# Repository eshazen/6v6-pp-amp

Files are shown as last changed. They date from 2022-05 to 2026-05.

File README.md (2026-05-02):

# 10 WPC 6V6 push-pull amp

This is a proposed build of an amp for TV sound.  I've been using a
6V6 single-ended amp, which is OK but perhaps a little wimpy for this
application.  The Dynaco A-410 EL84/6V6 schematic looks like a nice,
classic option.

As of 2026-04-02:

DigiKey parts are about $560 including iron.

Tubes:

    JJ 6SL7 2 @ $26.95  $45
    JJ 6V6  4 @ $23.95  $96
    JJ GZ34 1 @ $21.95  $22
                 Total $163

PCBs from JLC almost $200 with shipping.
<br>PCBGOGO $178 with shipping
				 
So around $950 total without chassis. Amps are now expensive!

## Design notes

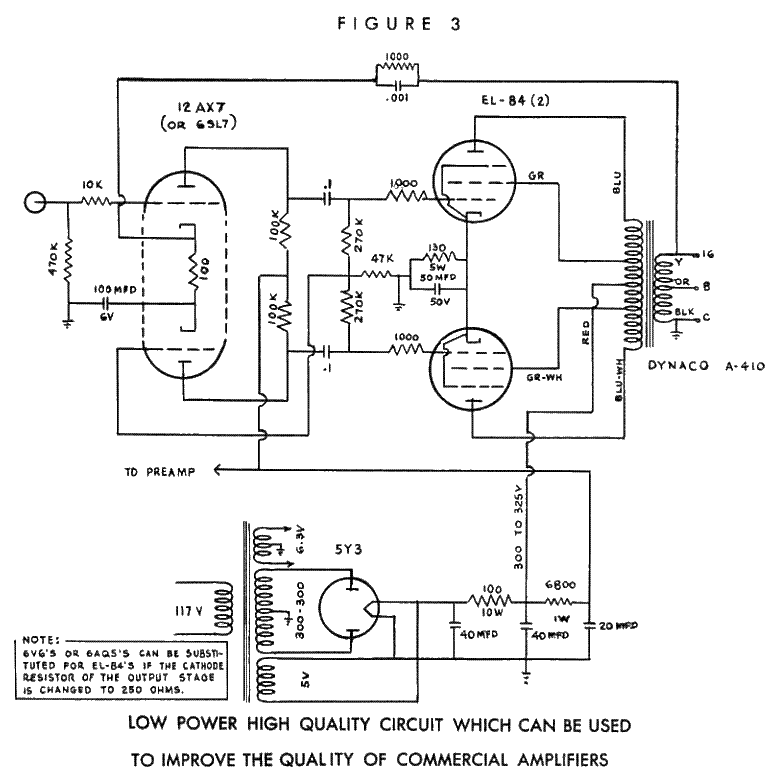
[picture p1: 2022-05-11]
reference/Push-Pull-EL84-6BQ5-6V6-6AQ5-Dynaco-A-410-Tube-Amp-Schematic.png

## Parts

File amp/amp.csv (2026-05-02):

Reference | Value | Qty | DNP | CatNo
C1,C9 | 1000p | 2 |  | 399-5448-1-ND
C2,C10 | 100u 16V | 2 |  | 732-8598-1-ND
C3,C11 | 22u 350V | 2 |  | 493-12650-1-ND
C4,C5,C12,C13 | 0.22u 400V | 4 |  | 338-3444-ND
C6 | 47uF 450V | 1 |  | 399-15673-ND
C7,C14 | 470u 50V | 2 |  | 493-12789-1-ND
C8,C15 | 47u 450V | 2 |  | 399-15673-ND
F1 | Fuse | 1 |  | Mouser 504-BK/HBH-I-R
H1,H2,H3,H4 | MountingHole | 4
J1,J3 | RCA | 2 |  | PJRAN1X1U03X-ND
J2 | Conn_01x05 | 1 |  | 486-1007-ND
J4,J5 | JPR_2x3 | 2 |  | 2057-PH2-06-UA-ND
JP1 | JPR3 | 1 |  | WM4621-ND
LS1,LS2 | Speaker | 2 |  | 36-4109-ND
NE1 | Lamp_Neon | 1 |  | A1A-ND
R1,R15 | 470K | 2 |  | 470KW-1-ND
R2,R4,R16,R18 | 100K | 4 |  | 100KW-1-ND
R3,R17 | 100 | 2 |  | 100W-1-ND
R5,R10,R14,R19,R24,R27 | 1k | 6 |  | RSA-1.0KRCT-ND
R6,R20 | 6.8k 1W | 2 |  | 6.8KW-1-ND
R7,R9,R21,R23 | 270K | 4 |  | 270KW-1-ND
R8,R22 | 47K | 2 |  | 47KW-1-ND
R11,R13,R26 | 100R 20W | 3 |  | B20J100E-ND
R12,R25 | 250 | 2 |  | PPC1D250CT-ND
R28 | 100k | 1 |  | 100KW-1-ND
SW1 | SW_SPST_GND | 1 |  | 563-1727-ND
SW2,SW3 | SW_SPDT | 2 |  | 563-1727-ND
T1 | Transformer_Hammond_272HX | 1 |  | HM5012-ND
T2,T3 | Hammond 1608A | 2 |  | HM4113-ND
U1,U5 | 6SL7 | 2 |  | AES P-ST8-193
U2 | GZ34 | 1 |  | AES P-ST8-193
U3,U4,U6,U7 | 6V6 | 4 |  | AES P-ST8-193

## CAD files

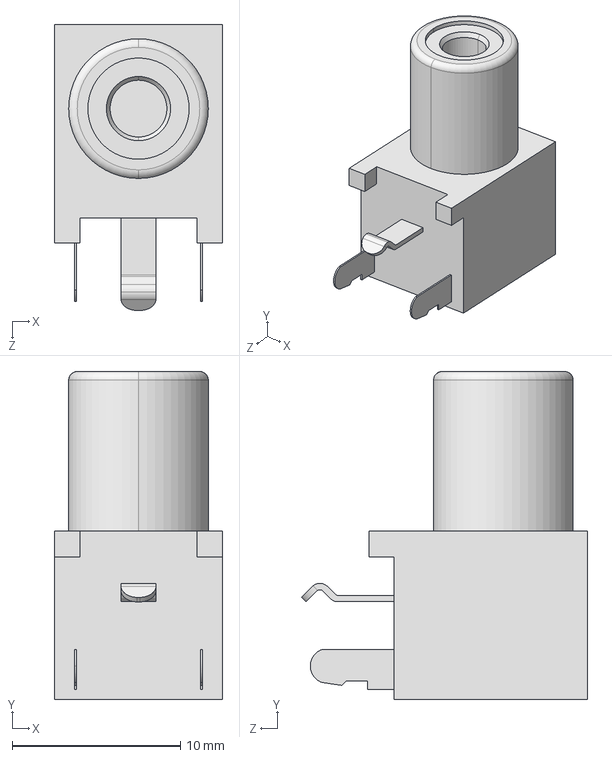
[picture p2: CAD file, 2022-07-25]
amp/3D/pjran1x1_Series.STEP
10.00 x 19.5 x 17.0 mm

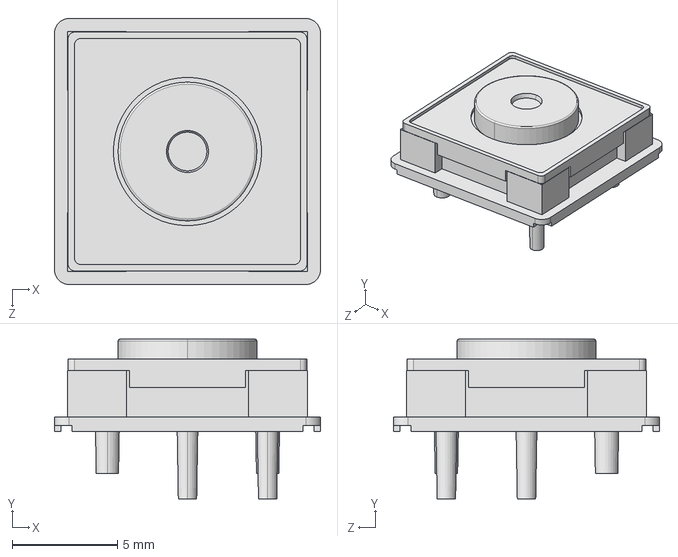
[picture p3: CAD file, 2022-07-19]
amp/3D/1241.1002.STEP
12.7 x 7.60 x 12.7 mm

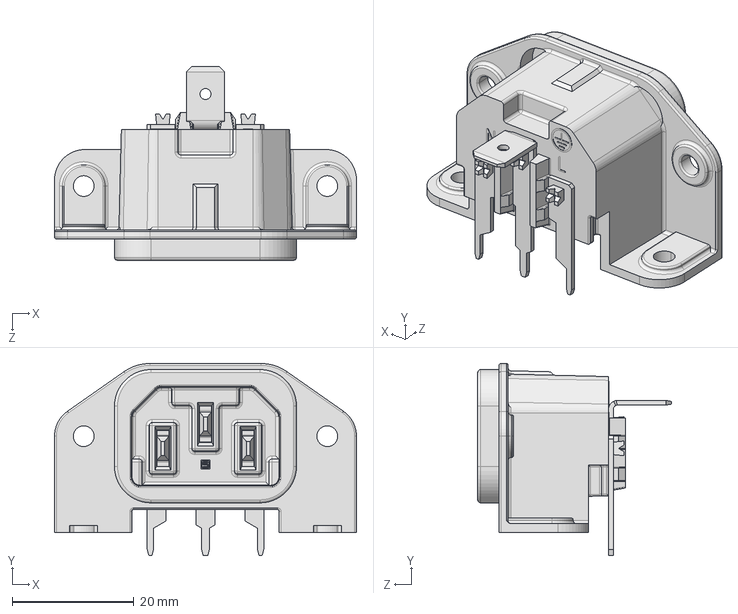
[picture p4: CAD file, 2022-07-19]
amp/3D/e_0100.2041d003.step
49.6 x 31.6 x 31.8 mm

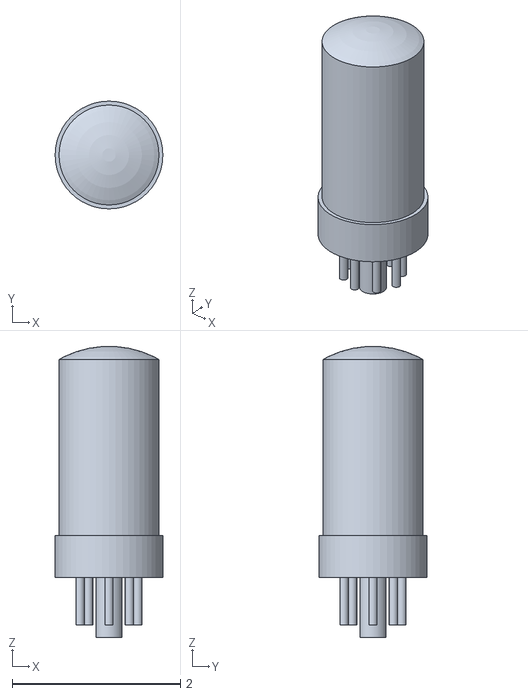
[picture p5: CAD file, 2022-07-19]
amp/3D/6sl7.stl
1.28 x 1.28 x 3.46

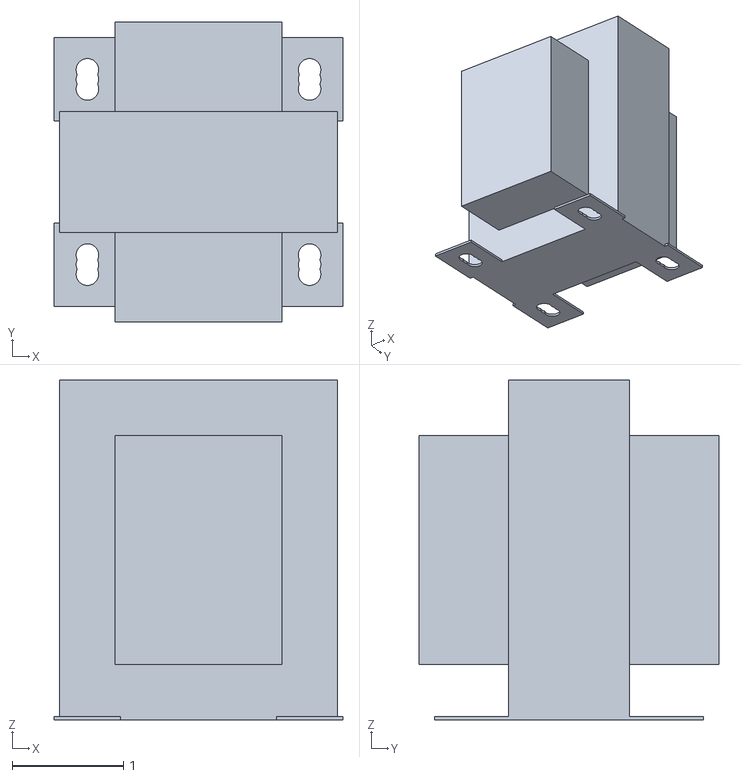
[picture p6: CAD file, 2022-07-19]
amp/3D/hammond_1608a.stl
2.60 x 2.70 x 3.06

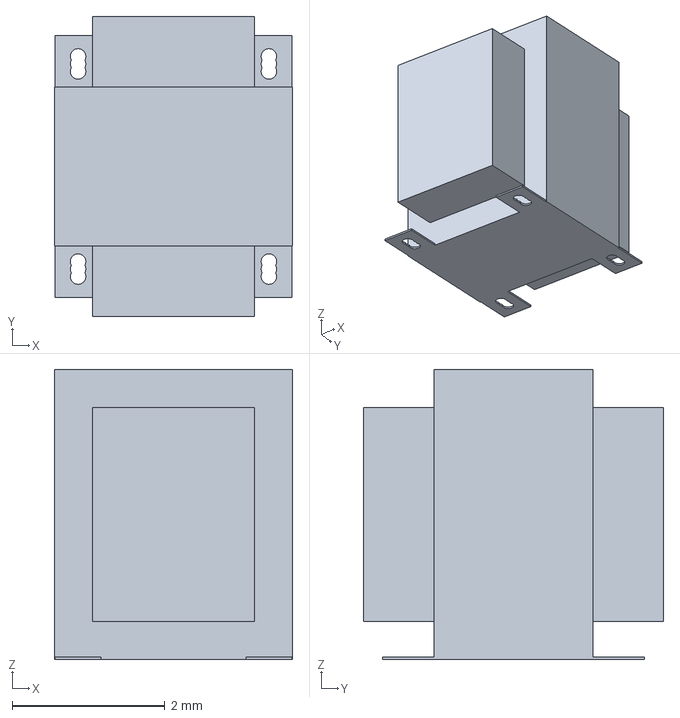
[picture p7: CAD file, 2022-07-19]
amp/3D/hammond_272hx.3mf
3.12 x 3.94 x 3.80 mm

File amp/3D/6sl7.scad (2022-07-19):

/* Generic octal tube */

e = 0.001;
$fn=48;

base_dia = 1+9/32;
tube_dia = 1+3/16;
overall_height = 3+5/16;
working_height = 2.75;

base_height = 0.5;

glass_height = working_height-base_height;
pin_len = overall_height-working_height;

/* must be >2 */
sphere_dia = 2.05 * tube_dia;

pin_rad = (11/16) / 2;
pin_dia = 0.1;
post_dia = 5/16;
post_len = pin_len + 0.15;

pstep = 360/8;

module tube() {
     /* base */
     color("black")
	  cylinder( h=base_height, d=base_dia);
     /* glass with rounded top */
     color( [0.5, 0.5, 0.5, 0.75])
     intersection() {
	  cylinder( h=working_height, d=tube_dia);
	  translate( [0, 0, working_height-sphere_dia/2])
	       sphere( d=sphere_dia);
     }
     /* array of pins */
     color("silver")
     for( i= [0: 8]) {
	  rotate( [0, 0, i*pstep])
	       translate( [pin_rad, 0, -pin_len])
	       cylinder( r=pin_dia/2, h=pin_len);
     }

     /* post */
     color("black")
     translate( [0, 0, -post_len])
	  cylinder( d=post_dia, h=post_len);
}



tube();

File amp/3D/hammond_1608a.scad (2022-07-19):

/* Hammond 1608A audio */


$fn=32;
e = 0.001;

/* datasheet dims */
A = 2.500;
B = 2.700;
C = 3.060;;
D = 2.000;
E = 1.667;
GX = 0.203;
GY = 0.375;

/* core dims (estimated) */
core_X = A;
core_Y = E-GY-0.2;
core_Z = C;

/* bell dims (estimated) */
bell_X = A-1.0;
bell_Y = B;
bell_Z = C-1.0;
bell_up = 0.5;

/* mounting tabs */
tab_X = 0.6;
tab_Y = 0.75;
tab_Z = 0.03125;

module tab() {
     difference() {
	  cube( [tab_X, tab_Y, tab_Z]);
	  translate( [tab_X/2, tab_Y/2+GY/2-GX/2, -e])
	       cylinder( d=GX, h=tab_Z+2*e);
	  translate( [tab_X/2, tab_Y/2-GY/2+GX/2, -e])
	       cylinder( d=GX, h=tab_Z+2*e);
	  translate( [tab_X/2, tab_Y/2, -e])
	       cylinder( d=GX, h=tab_Z+2*e);
     }
}

module 272hx() {
     color( [0.3, 0.3, 0.3]) {
	  /* core */
	  translate( [-core_X/2, -core_Y/2, 0])
	       cube( [core_X, core_Y, core_Z]);
	  /* bell */
	  translate( [-bell_X/2, -bell_Y/2, bell_up])
	       cube( [bell_X, bell_Y, bell_Z]);
	  translate( [-(D/2)-tab_X/2, -E/2-tab_Y/2, 0])
	       tab();
	  translate( [(D/2)-tab_X/2, -E/2-tab_Y/2, 0])
	       tab();
	  translate( [-(D/2)-tab_X/2, E/2-tab_Y/2, 0])
	       tab();
	  translate( [(D/2)-tab_X/2, E/2-tab_Y/2, 0])
	       tab();
     }
}


272hx();

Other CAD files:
amp/3D/hammond_272hx.scad
amp/3D/hammond_272hx.stl

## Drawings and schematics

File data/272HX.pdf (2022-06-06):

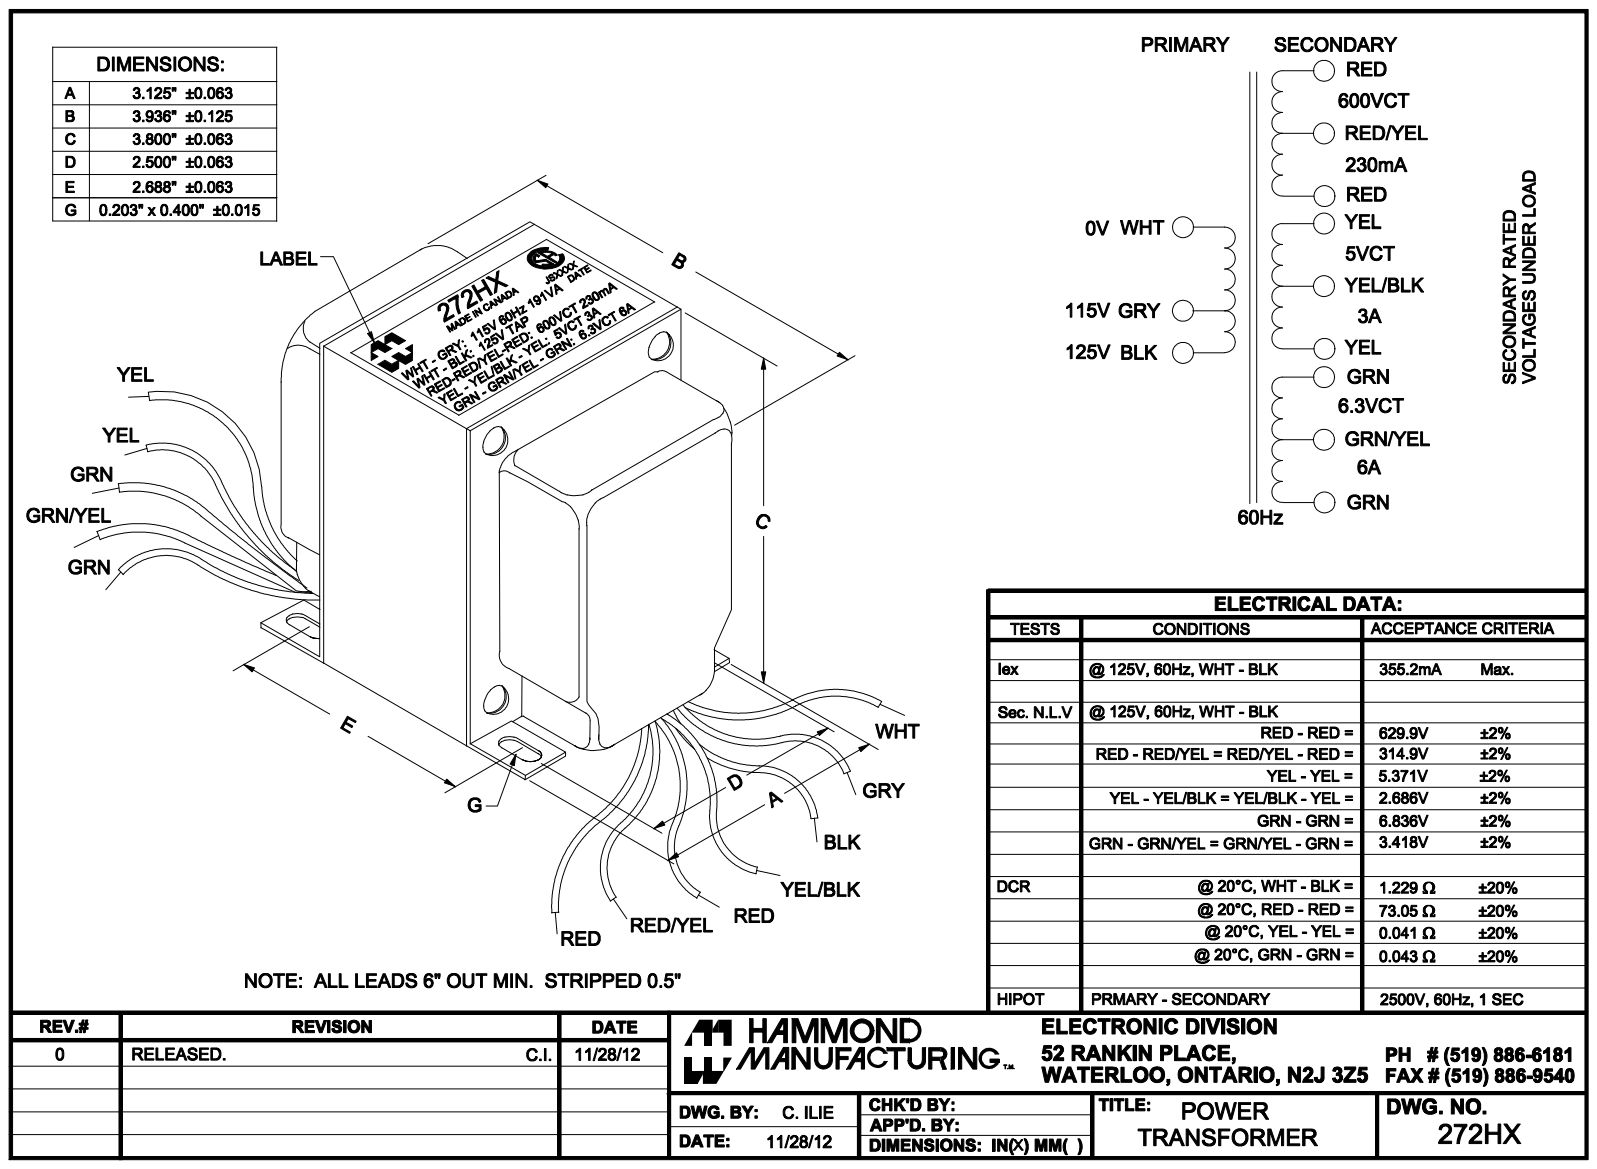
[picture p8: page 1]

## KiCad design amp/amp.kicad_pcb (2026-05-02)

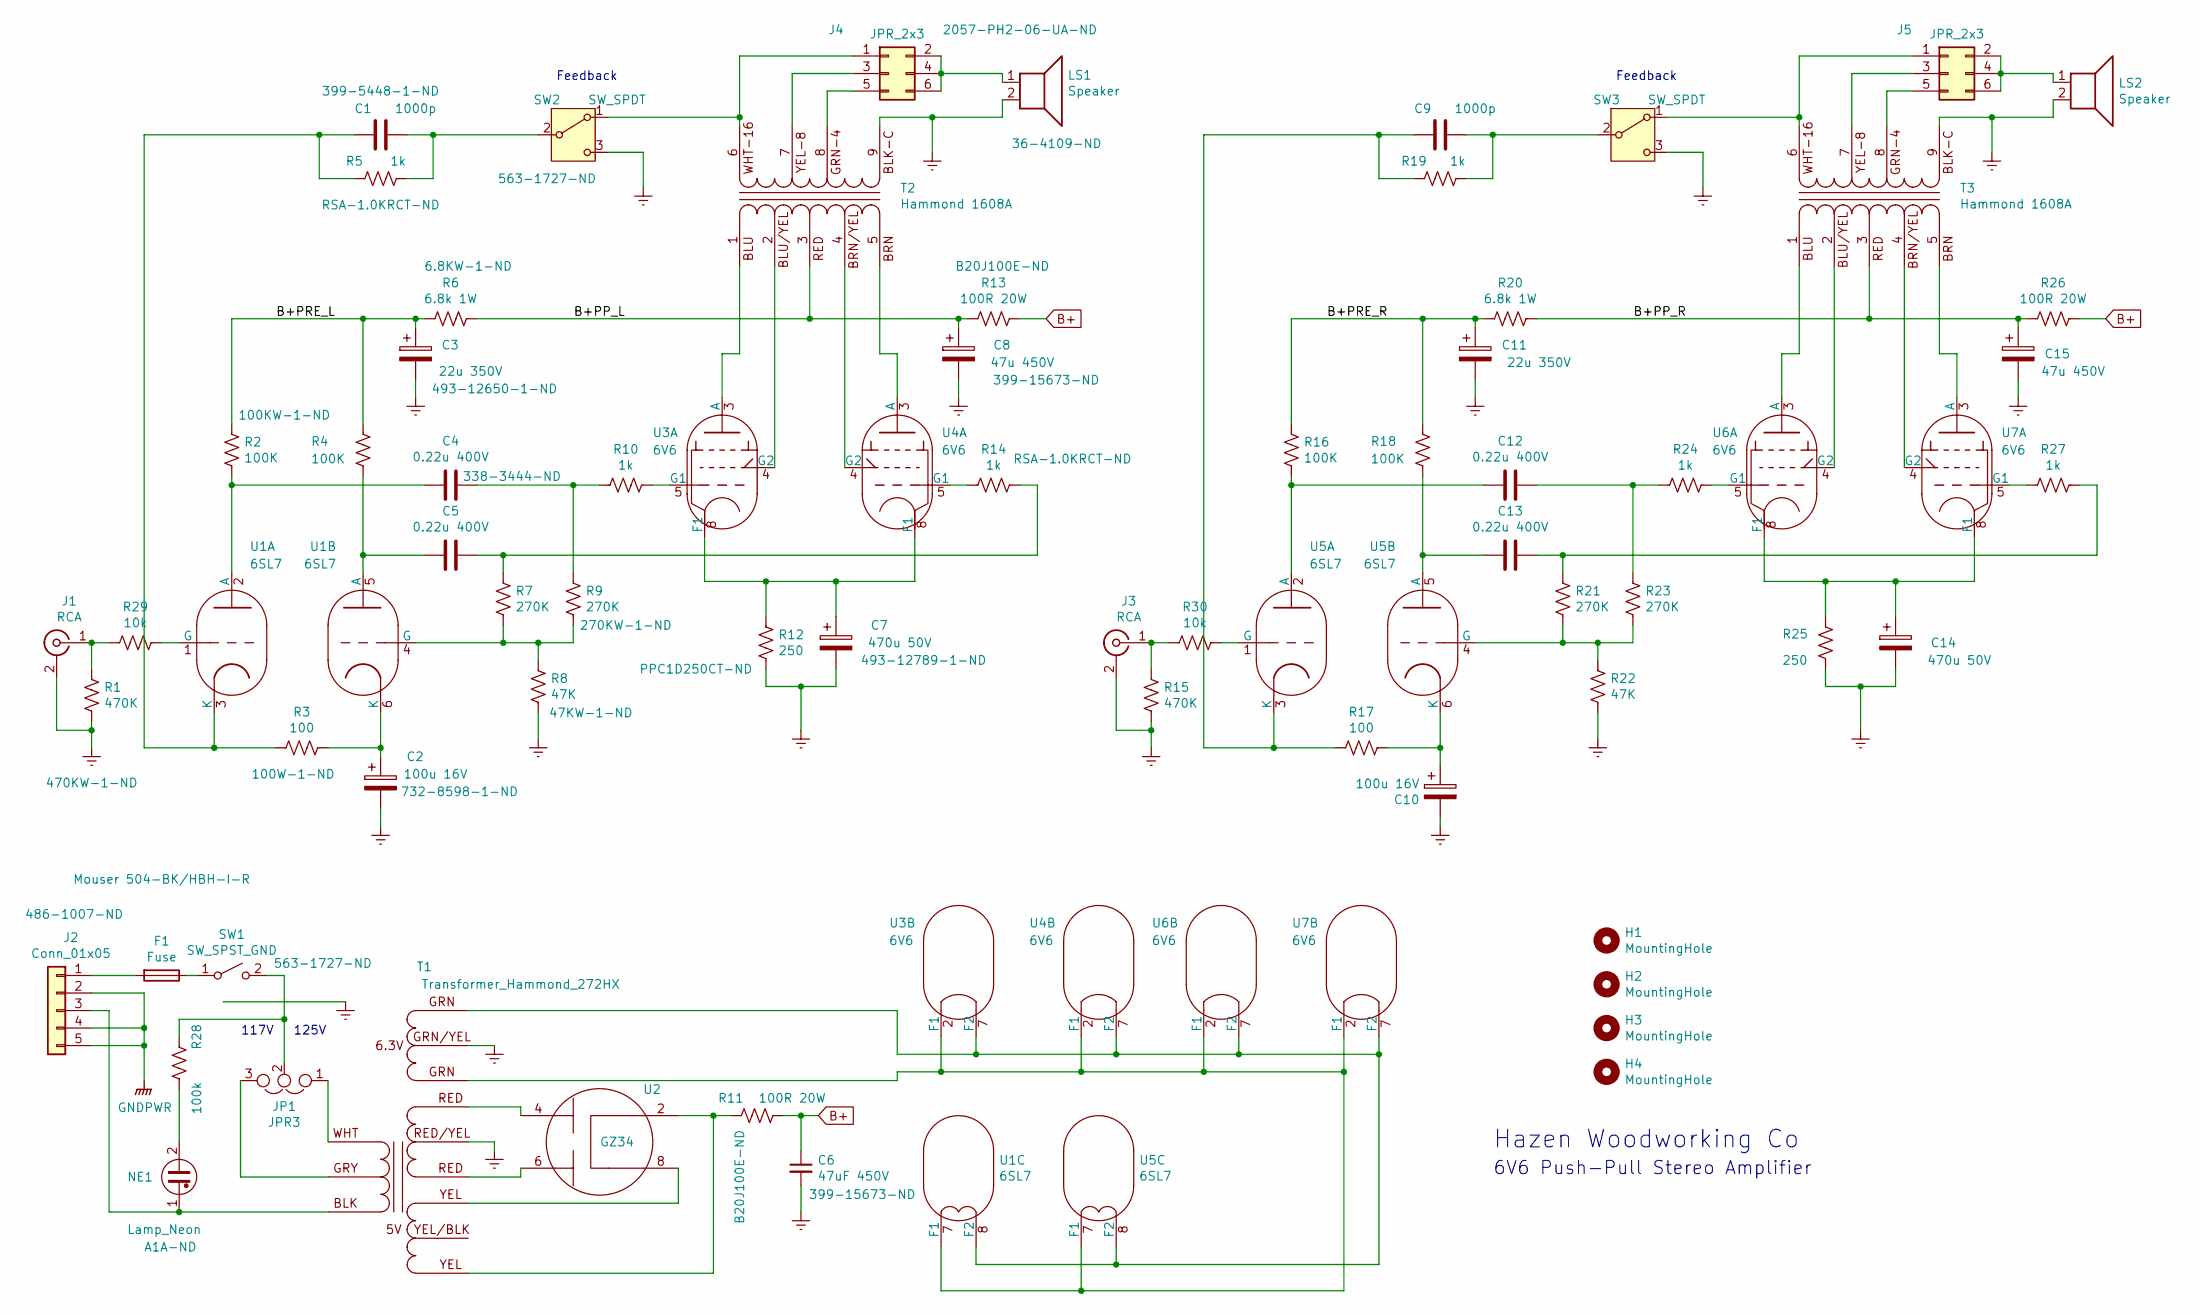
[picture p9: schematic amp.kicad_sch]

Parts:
C1, C9: 1000p; C_Rect_L7.2mm_W2.5mm_P5.00mm_FKS2_FKP2_MKS2_MKP2
C2, C10: 100u 16V; CP_Radial_D5.0mm_P2.00mm
C3, C11: 22u 350V; CP_Radial_D12.5mm_P5.00mm
C4, C5, C12, C13: 0.22u 400V; cap_rect_32x14_P18.3mm
C6: 47uF 450V; CP_Radial_D16.0mm_P7.50mm
C7, C14: 470u 50V; CP_Radial_D12.5mm_P5.00mm
C8, C15: 47u 450V; CP_Radial_D16.0mm_P7.50mm
F1: Fuse; HBH-I-R
H1, H2, H3, H4: MountingHole; Mtg6-32
J1, J3: RCA; PRJAN1X1
J2: Conn_01x05; GSP1.8101.1
J4, J5: JPR_2x3; PinHeader_2x03_P2.54mm_Vertical
JP1: JPR3; Molex_KK-396_A-41791-0003_1x03_P3.96mm_Vertical
LS1, LS2: Speaker; Keystone_4109
NE1: Lamp_Neon; A1A
R1, R15: 470K; R_Axial_DIN0411_L9.9mm_D3.6mm_P12.70mm_Horizontal
R2, R4, R16, R18: 100K; R_Axial_DIN0414_L11.9mm_D4.5mm_P15.24mm_Horizontal
R3, R17: 100; R_Axial_DIN0414_L11.9mm_D4.5mm_P15.24mm_Horizontal
R5, R10, R14, R19, R24, R27: 1k; R_Axial_DIN0411_L9.9mm_D3.6mm_P12.70mm_Horizontal
R6, R20: 6.8k 1W; R_Axial_DIN0414_L11.9mm_D4.5mm_P15.24mm_Horizontal
R7, R9, R21, R23: 270K; R_Axial_DIN0414_L11.9mm_D4.5mm_P15.24mm_Horizontal
R8, R22: 47K; R_Axial_DIN0411_L9.9mm_D3.6mm_P12.70mm_Horizontal
R11, R13, R26: 100R 20W; R_100R_20W_11x51mm
R12, R25: 250; R_Axial_DIN0414_L11.9mm_D4.5mm_P15.24mm_Horizontal
R28: 100k; R_Axial_DIN0414_L11.9mm_D4.5mm_P15.24mm_Horizontal
R29, R30: 10k; R_Axial_DIN0414_L11.9mm_D4.5mm_P15.24mm_Horizontal
SW1: SW_SPST_GND; 8GA1016-Z
SW2, SW3: SW_SPDT; 8GA1016-Z
T1: Transformer_Hammond_272HX; Hammond_272HX
T2, T3: Hammond 1608A; Hammond_1608A
U1, U5: 6SL7; Octal_Socket_P-ST8-193
U2: GZ34; Octal_Socket_P-ST8-193
U3, U4, U6, U7: 6V6; Octal_Socket_P-ST8-193

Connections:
/B+PP_L: C8.1, R6.1, R13.2, T2.3 (RED)
/B+PP_R: C15.1, R20.1, R26.2, T3.3 (RED)
/B+PRE_L: C3.1, R2.1, R4.1, R6.2
/B+PRE_R: C11.1, R16.1, R18.1, R20.2
B+: C6.1, R11.1, R13.1, R26.1
Earth: C2.2, C3.2, C6.2, C7.2, C8.2, C10.2, C11.2, C14.2, C15.2, J1.2 (Ext), J3.2 (Ext), LS1.2, LS2.2, R1.2, R8.2, R12.2, R15.2, R22.2, R25.2, SW1.4 (G1), SW2.3 (C), SW3.3 (C), T1.8 (SC), T1.11 (FC), T2.9 (BLK), T3.9 (BLK)
GNDPWR: J2.2, J2.4, J2.5
unnamed: C4.1, R9.1, R10.2
unnamed: C5.1, R7.1, R14.1
unnamed: C12.1, R23.1, R24.2
unnamed: C13.1, R21.1, R27.1
unnamed: J1.1 (In), R1.1, R29.2
unnamed: F1.2, J2.1
unnamed: J2.3, NE1.1, T1.3 (AB)
unnamed: J3.1 (In), R15.1, R30.2
unnamed: J4.1, SW2.1 (A), T2.6 (WHT)
unnamed: J4.2, J4.4, J4.6, LS1.1
unnamed: J4.3, T2.7 (YEL)
unnamed: J4.5, T2.8 (GRN)
unnamed: J5.1, SW3.1 (A), T3.6 (WHT)
unnamed: J5.2, J5.4, J5.6, LS2.1
unnamed: J5.3, T3.7 (YEL)
unnamed: J5.5, T3.8 (GRN)
unnamed: NE1.2, R28.1
unnamed: F1.1, SW1.1 (A)
unnamed: JP1.2, R28.2, SW1.2 (B)
unnamed: C1.1, R5.1, SW2.2 (B)
unnamed: C9.1, R19.1, SW3.2 (B)
unnamed: JP1.1, T1.1 (AA)
unnamed: JP1.3, T1.2 (AC)
unnamed: T1.10 (FA), U1.7 (F1), U3.2 (F1), U4.2 (F1), U5.7 (F1), U6.2 (F1), U7.2 (F1)
unnamed: T1.12 (FB), U1.8 (F2), U3.7 (F2), U4.7 (F2), U5.8 (F2), U6.7 (F2), U7.7 (F2)
unnamed: T2.1 (BLU), U3.3 (A)
unnamed: T2.2 (BLU/YEL), U3.4 (G2)
unnamed: T2.5 (BRN), U4.3 (A)
unnamed: T2.4 (BRN/YEL), U4.4 (G2)
unnamed: T3.1 (BLU), U6.3 (A)
unnamed: T3.2 (BLU/YEL), U6.4 (G2)
unnamed: T3.5 (BRN), U7.3 (A)
unnamed: T3.4 (BRN/YEL), U7.4 (G2)
unnamed: C4.2, R2.2, U1.2 (A)
unnamed: R29.1, U1.1 (G)
unnamed: C1.2, R3.2, R5.2, U1.3 (K)
unnamed: C5.2, R4.2, U1.5 (A)
unnamed: R7.2, R8.1, R9.2, U1.4 (G)
unnamed: C2.1, R3.1, U1.6 (K)
unnamed: T1.9 (SB), U2.4 (A1)
unnamed: T1.7 (SA), U2.6 (A2)
unnamed: T1.6 (SB), U2.8 (F2)
unnamed: R11.2, T1.4 (SA), U2.2 (K)
unnamed: C7.1, R12.1, U3.8 (F1), U4.8 (F1)
unnamed: R10.1, U3.5 (G1)
unnamed: R14.2, U4.5 (G1)
unnamed: C12.2, R16.2, U5.2 (A)
unnamed: R30.1, U5.1 (G)
unnamed: C9.2, R17.2, R19.2, U5.3 (K)
unnamed: C13.2, R18.2, U5.5 (A)
unnamed: R21.2, R22.1, R23.2, U5.4 (G)
unnamed: C10.1, R17.1, U5.6 (K)
unnamed: C14.1, R25.1, U6.8 (F1), U7.8 (F1)
unnamed: R24.1, U6.5 (G1)
unnamed: R27.2, U7.5 (G1)

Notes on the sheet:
117V
125V
Feedback
6V6 Push-Pull Stereo Amplifier
Hazen Woodworking Co

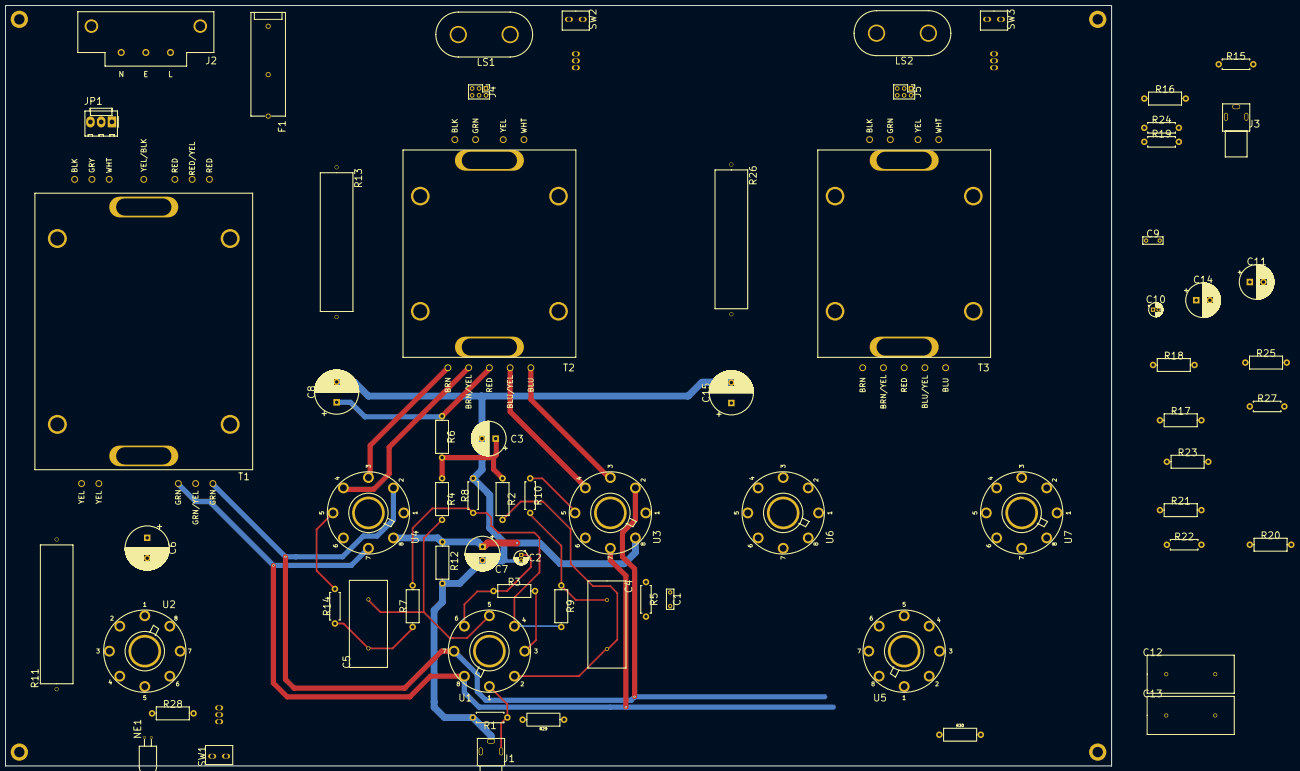
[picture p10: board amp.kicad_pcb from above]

Board: 2 copper layers, 406.4 x 279.4 mm, 72 parts (0 on the bottom side), 62 nets.

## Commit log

2022-05-12 First draft amp schematic
    [amp.kicad_pcb, amp.sch]
2022-06-05 draft stereo schem complete
    [amp.sch]
2022-06-06 starting footprints
    [amp.sch]
2022-06-06 working on schem
    [amp.sch]
2022-06-17 assigning part numbers
    [amp.sch]
2022-06-17 All CatNo filled in
    [amp.sch]
2022-07-18 all footprinted with a few issues
    [amp.kicad_pcb, amp.sch]
2022-07-19 starting 3D
    [amp.kicad_pcb, amp.sch, hammond_272hx.3mf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]
2022-07-19 3D models
    [6sl7.scad, 6sl7.stl, amp.kicad_pcb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]
2022-07-19 3D work
    [1241.1002.STEP, amp.kicad_pcb, e_0100.2041d003.step]
2022-07-25 placement in progress
    [amp.kicad_pcb, pjran1x1_Series.STEP]
2022-08-18 draft routing one channel
    [amp.kicad_pcb]
2026-05-02 update notes and schematic
    [amp-B_Cu.gbr, amp-B_Mask.gbr, amp-B_Paste.gbr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]
2026-05-02 notes and add grid stoppers to schem
    [amp.kicad_pcb, amp.kicad_sch]
